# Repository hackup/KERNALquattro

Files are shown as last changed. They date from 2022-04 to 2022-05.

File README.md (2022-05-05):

# KERNALquattro

The KERNALquattro is a compact, versatile, and still relatively cheap replacement for 2364 ROMs as found in the Commodore 64 and other 8-bit computers of that time. It provides 32KB of memory using an AT28HC256 EEPROM, thus holding the equivalent of up to four 2364 ROMs. Those four banks can be selected using a DIP switch, solder bridges, or by external means using the connector.

An adapter board is provided which maps the pins of the KERNALquattro back to a 28C256 DIP EEPROM. This allows the EEPROM to be programmed using a standard programmer like the TL866.

See my [blog post](https://www.hackup.net/2022/05/the-kernal-quattro-a-2364-rom-replacement/) for more details.

 **USE AT YOUR OWN RISK!**.

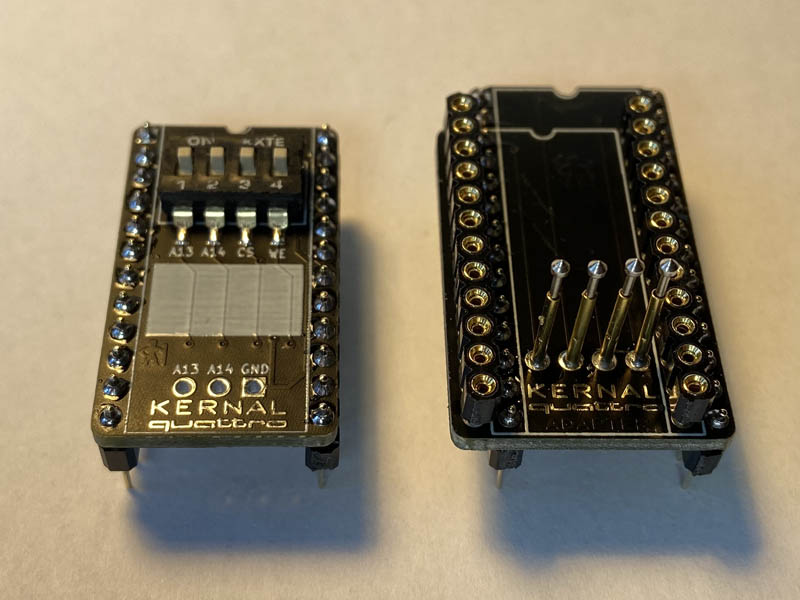
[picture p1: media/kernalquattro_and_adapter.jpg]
KERNALquattro and Adapter


## License


This work is licensed under a
[Creative Commons Attribution-NonCommercial-ShareAlike 4.0 International License](http://creativecommons.org/licenses/by-nc-sa/4.0/).

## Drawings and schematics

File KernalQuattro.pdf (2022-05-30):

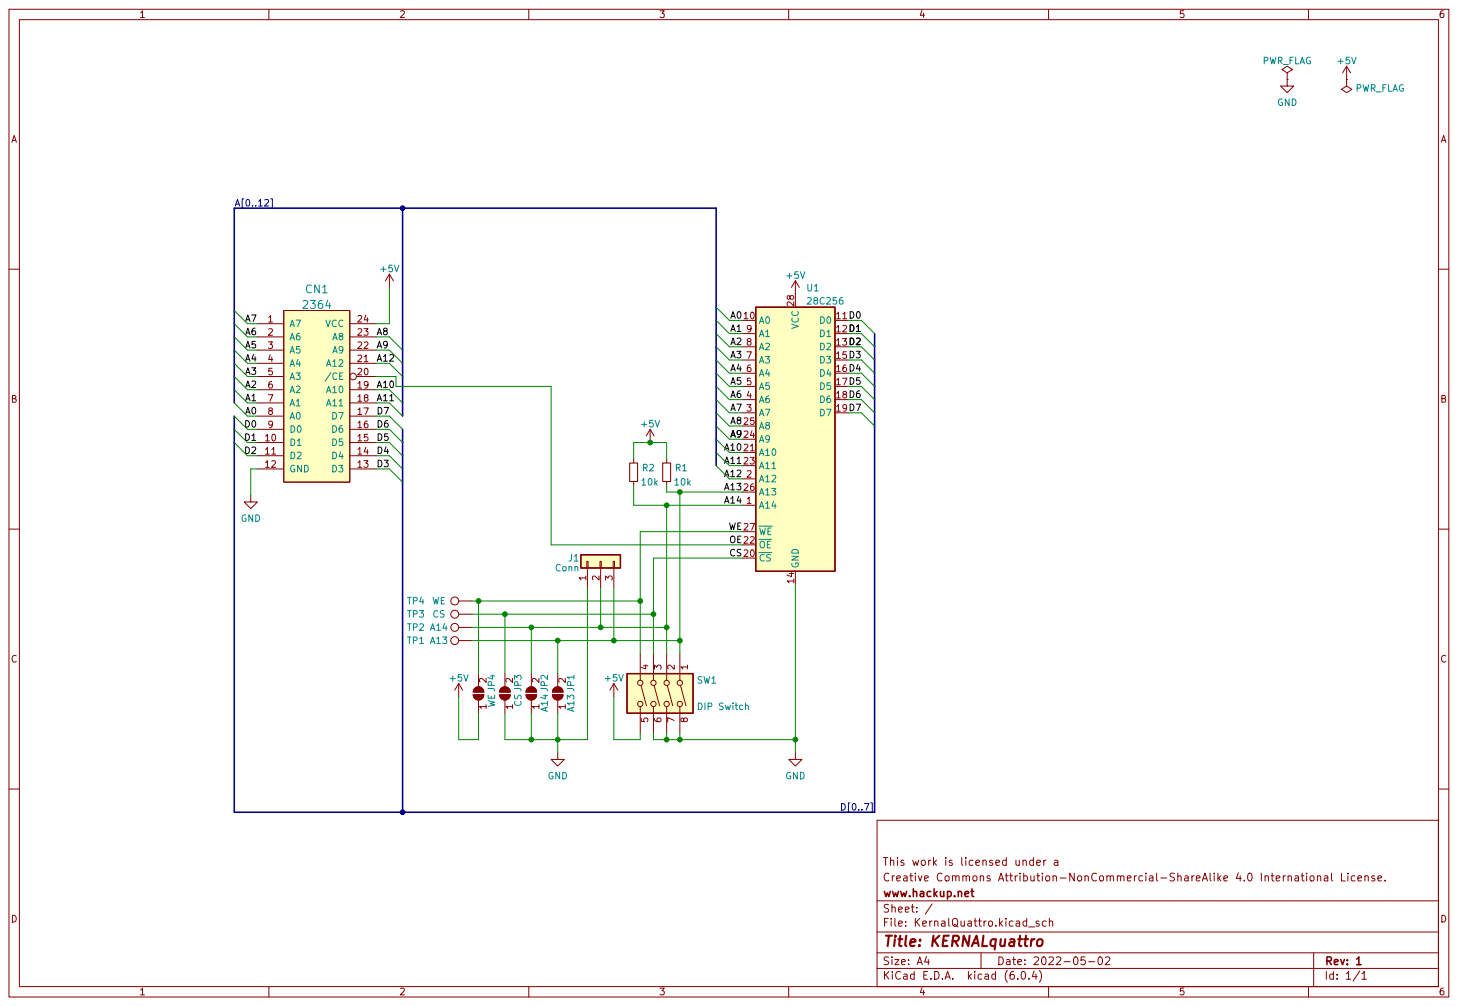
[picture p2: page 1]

File: KernalQuattro.kicad_sch Sheet: / www.hackup.net Creative Commons Attribution-NonCommercial-ShareAlike 4.0 International License. This work is licensed under a

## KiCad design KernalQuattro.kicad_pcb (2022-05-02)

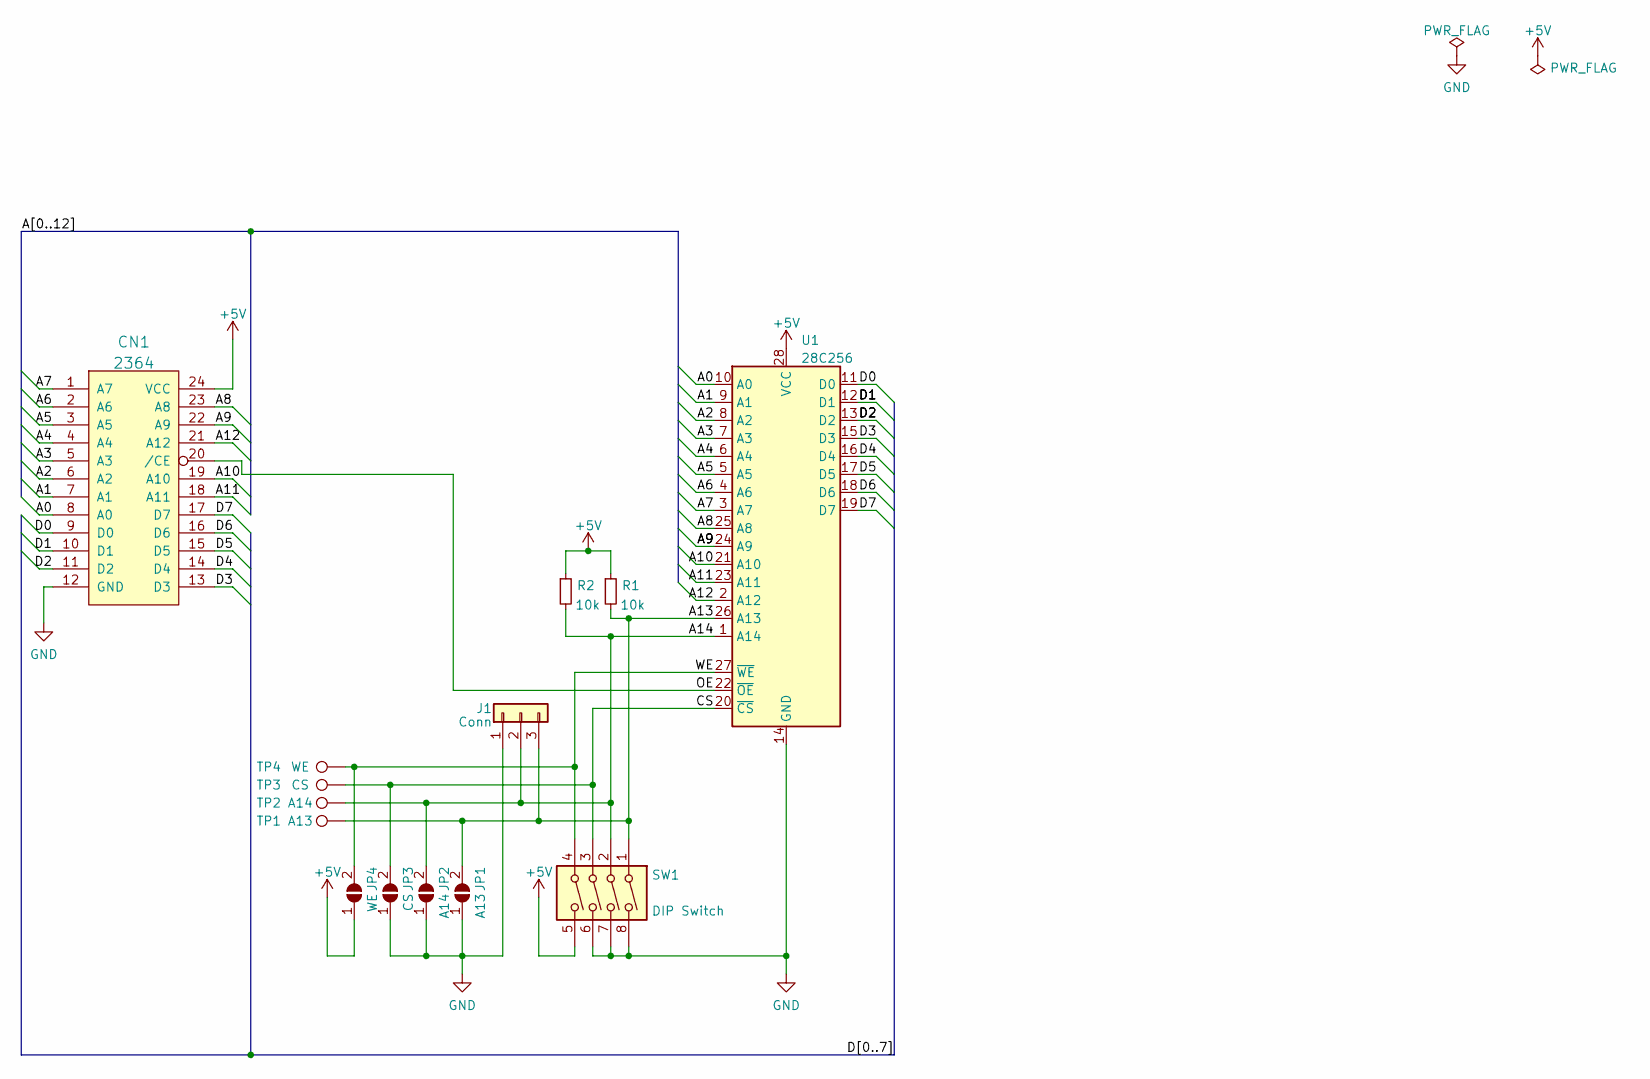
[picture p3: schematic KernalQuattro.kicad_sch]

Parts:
CN1: 2364; DIP-24_W15.24mm_Socket
J1: Conn; PinHeader_1x03_P2.54mm_Horizontal
JP1: A13; SolderJumper-2_slim
JP2: A14; SolderJumper-2_slim
JP3: CS; SolderJumper-2_slim
JP4: WE; SolderJumper-2_slim
R1, R2: 10k; R_0805_2012Metric
SW1: DIP Switch; SW_DIP_SPSTx04_Slide_6.7x11.72mm_W8.61mm_P2.54mm_LowProfile
TP1: A13; TestPoint_Pad_D1.5mm
TP2: A14; TestPoint_Pad_D1.5mm
TP3: CS; TestPoint_Pad_D1.5mm
TP4: WE; TestPoint_Pad_D1.5mm
U1: 28C256; SOIC-28W_7.5x17.9mm_P1.27mm

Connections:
+5V: CN1.24 (VCC), JP4.1 (A), R1.1, R2.1, SW1.5, U1.28 (VCC)
/A0: CN1.8 (A0), U1.10 (A0)
/A1: CN1.7 (A1), U1.9 (A1)
/A2: CN1.6 (A2), U1.8 (A2)
/A3: CN1.5 (A3), U1.7 (A3)
/A4: CN1.4 (A4), U1.6 (A4)
/A5: CN1.3 (A5), U1.5 (A5)
/A6: CN1.2 (A6), U1.4 (A6)
/A7: CN1.1 (A7), U1.3 (A7)
/A8: CN1.23 (A8), U1.25 (A8)
/A9: CN1.22 (A9), U1.24 (A9)
/A10: CN1.19 (A10), U1.21 (A10)
/A11: CN1.18 (A11), U1.23 (A11)
/A12: CN1.21 (A12), U1.2 (A12)
/A13: J1.3, JP1.2 (B), R1.2, SW1.1, TP1.1, U1.26 (A13)
/A14: J1.2, JP2.2 (B), R2.2, SW1.2, TP2.1, U1.1 (A14)
/CS: JP3.2 (B), SW1.3, TP3.1, U1.20 (~CS)
/D0: CN1.9 (D0), U1.11 (D0)
/D1: CN1.10 (D1), U1.12 (D1)
/D2: CN1.11 (D2), U1.13 (D2)
/D3: CN1.13 (D3), U1.15 (D3)
/D4: CN1.14 (D4), U1.16 (D4)
/D5: CN1.15 (D5), U1.17 (D5)
/D6: CN1.16 (D6), U1.18 (D6)
/D7: CN1.17 (D7), U1.19 (D7)
/OE: CN1.20 (/CE), U1.22 (~OE)
/WE: JP4.2 (B), SW1.4, TP4.1, U1.27 (~WE)
GND: CN1.12 (GND), J1.1, JP1.1 (A), JP2.1 (A), JP3.1 (A), SW1.6, SW1.7, SW1.8, U1.14 (GND)

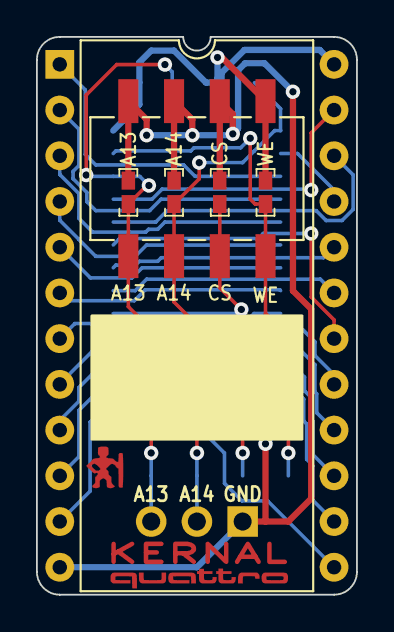
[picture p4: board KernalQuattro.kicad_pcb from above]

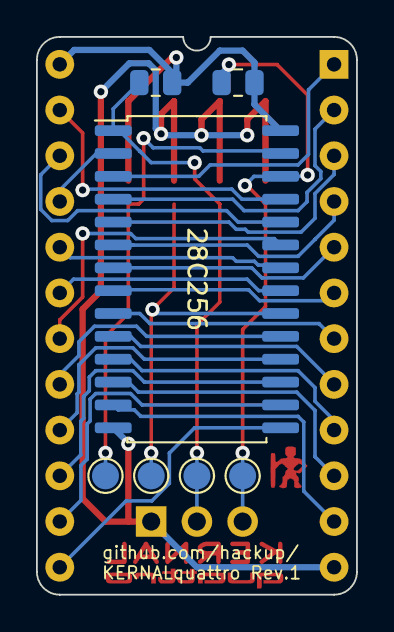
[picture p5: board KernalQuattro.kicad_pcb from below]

Board: 2 copper layers, 17.8 x 31.0 mm, 14 parts (7 on the bottom side), 28 nets.

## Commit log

2022-04-06 Initial import, work in progress.
    [Compact23256.kicad_pcb, Compact23256.kicad_sch]
2022-04-07 Work in progress.
    [Compact23256.kicad_pcb, Compact23256.kicad_sch]
2022-04-09 Renamed project.
    [KernalQuattro.kicad_pcb, KernalQuattro.kicad_sch]
2022-04-09 Rounded corners.
    [KernalQuattro.kicad_pcb, KernalQuattro.kicad_sch]
2022-04-09 Added programming adapter.
    [KQAdapter.kicad_pcb, KQAdapter.kicad_sch]
2022-04-11 Added custom pin header model.
    [KernalQuattro.kicad_pcb]
2022-04-20 Generate Gerber files.
    [KQAdapter.kicad_pcb, KernalQuattro.kicad_pcb]
2022-05-02 Added license information.
    [KQAdapter.kicad_pcb, KQAdapter.kicad_sch, KernalQuattro.kicad_pcb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]
2022-05-30 Added schematics export to repo.
